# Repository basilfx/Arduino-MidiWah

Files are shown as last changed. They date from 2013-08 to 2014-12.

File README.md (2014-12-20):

# MidiWah v1.0
Arduino based bridge between a wah-wah (e.g. Dunlop GCB-95) and its potentiometer. Digitizes the potentiometer and feeds it via a digital potentiometer back to the circuit.

As a bonus, the digitized potentiometer signal can be  outputted via MIDI OUT.

## Contents
* Eagle schematic and PCB
* Arduino firmware

## Eagle

### Bill of materials
An Atmega328 can also be used. The R7-R9 are 0-ohm jumpers. The MCP4251 has a range of 0-100k.

| Part | Value | Device | Package |
|---|---|---|---|
| C1 | 22pF | C-EU025-024X044 | C025-024X044 |
| C2 | 22pF | C-EU025-024X044 | C025-024X044 |
| C3 | 1µF | CPOL-EUE2.5-5 | E2,5-5 |
| C4 | 1µF | CPOL-EUE2.5-5 | E2,5-5 |
| C5 | 100nF | C-EU025-024X044 | C025-024X044 |
| C6 | 100nF | C-EU025-024X044 | C025-024X044 |
| C7 | 100nF | C-EU025-024X044 | C025-024X044 |
| C8 | 100nF | C-EU025-024X044 | C025-024X044 |
| D1 | 1N4148 | 1N4148 | DO35-7 |
| IC1  | ATMEGA168 | MEGA8-P | DIL28-3 |
| IC2  | 7805L | 7805L | TO92 |
| IC3  | MCP4251 | MCP4251-104 | DIP254P762X533-14 |
| IC4  | 6N138 | 6N138 | DIL08 |
| Q1 | 16MHz | CRYSTALHC49S | HC49/S |
| R1 | 10k | R-EU_0204/7 | 0204/7 |
| R2 | 220 | R-EU_0204/7 | 0204/7 |
| R3 | 1k | R-EU_0204/7 | 0204/7 |
| R4 | 220 | R-EU_0204/7 | 0204/7 |
| R5 | 1k | R-EU_0204/7 | 0204/7 |
| R6 | 1k | R-EU_0204/2V | 0204V |
| R7 | 0 | R-EU_M0805 | M0805 |
| R8 | 0 | R-EU_M0805 | M0805 |
| R9 | 0 | R-EU_M0805 | M0805 |
| SW1  | | SW_DIP-4 | EDG-04 |

### Board render
The board measures 1.70x2.10 inch. Below a render of the top and bottom.

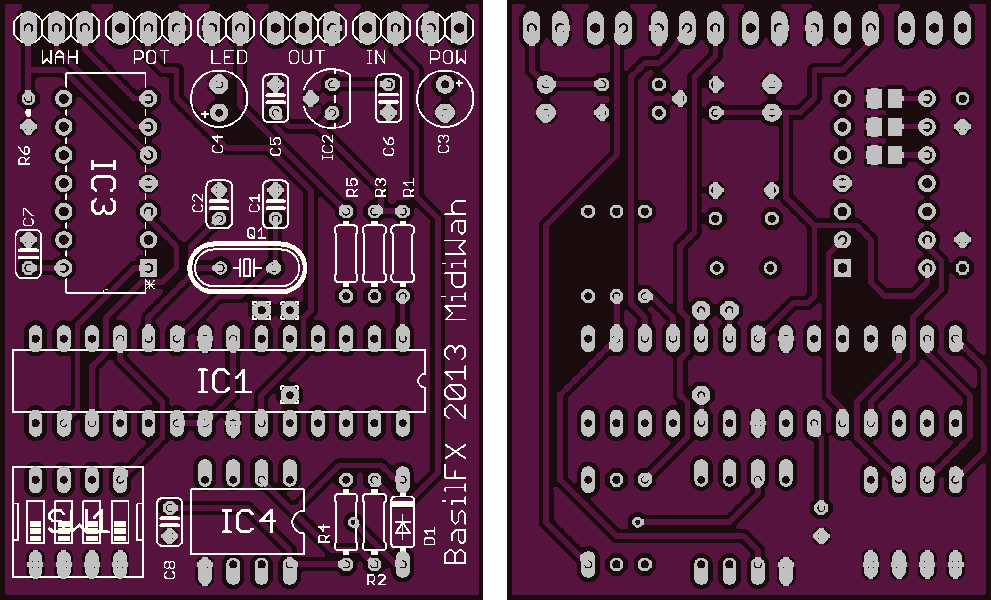
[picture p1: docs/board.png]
brd


## Arduino
The source can be found under `firmware`. It's build with Arduino 1.0.5, but newer versions should work too.

See the `firmware/UsedLibraries.md` for the libraries to install.

### Firmware
To be done.

### Configuration
The DIP switch on the PCB select the channel to which the MidiWah will respond

The firmware can be programmed via a few MIDI Control Change messages. Changes are only persisted when a save command is issued.

* `CC 80 [0|1]` &mdash; disable or enable calibration of the potentiometer. Replies with the same value.
* `CC 81 [0|1]` &mdash; disable or enable invertion of the potentiometer value. Replies with the same value.
* `CC 82 [0-2]` &mdash; select potentiometer program. Replies with the selected program, or the last one if program is invalid.
  * Program 0 is linear
  * Program 1 is logarithmic
  * Program 3 is first 50% from 0 to 127 and the next 50% from 127 to 0
* `CC 83 [x]` &mdash; save settings to EEPROM. The parameter `x` can be anything. Responds with same message.

## License
See the `LICENSE` file (MIT license).

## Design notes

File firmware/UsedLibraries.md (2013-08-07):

# Used Libraries
The libraries below are used and should be installed to compile this sketch.

## McpDigitalPot
Driver for the MCP4251 digital potentiometer.

URL: https://github.com/teabot/McpDigitalPot

## MIDI
MIDI protocol interface.

URL: http://playground.arduino.cc/Main/MIDILibrary

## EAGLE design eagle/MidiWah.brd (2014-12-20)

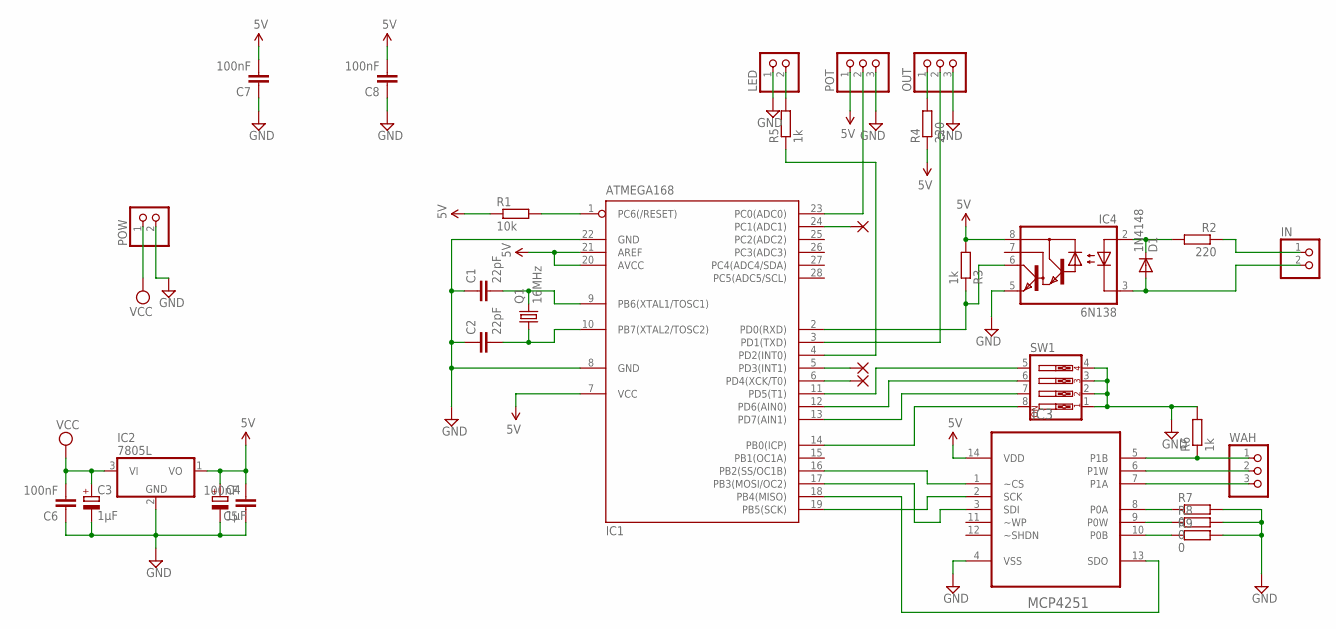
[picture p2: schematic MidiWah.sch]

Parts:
C1, C2: 22pF; C025-024X044
C3, C4: 1µF; E2,5-5
C5, C6, C7, C8: 100nF; C025-024X044
D1: 1N4148; DO35-7
IC1: ATMEGA168; DIL28-3
IC2: 7805L; TO92
IC3: MCP4251; DIP254P762X533-14
IC4: 6N138; DIL08
IN: PINHD-1X2; 1X02
LED: PINHD-1X2; 1X02
OUT: PINHD-1X3; 1X03
PAD1, PAD2, PAD3: WIREPAD1,6/0,8; 1,6/0,8
POT: PINHD-1X3; 1X03
POW: PINHD-1X2; 1X02
Q1: 16MHz; HC49/S
R1: 10k; 0204/7
R2, R4: 220; 0204/7
R3, R5: 1k; 0204/7
R6: 1k; 0204V
R7, R8, R9: 0; M0805
SW1: SW_DIP-4; EDG-04
WAH: PINHD-1X3; 1X03

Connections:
5V: C4.+, C5.2, C7.2, C8.2, IC1.7 (VCC), IC1.20 (AVCC), IC1.21 (AREF), IC2.1 (VO), IC3.14 (VDD), IC4.8 (VCC), POT.1, R1.1, R3.2, R4.1
GND: C1.1, C2.1, C3.-, C4.-, C5.1, C6.1, C7.1, C8.1, IC1.8 (GND), IC1.22 (GND), IC2.2 (GND), IC3.4 (VSS), IC4.5 (GND), LED.1, OUT.3, POT.3, POW.2, R6.2, R7.2, R8.2, R9.2, SW1.1, SW1.2, SW1.3, SW1.4
unnamed: IC1.1 (PC6(/RESET)), R1.2
unnamed: IC1.16 (PB2(SS/OC1B)), IC3.1 (~CS)
unnamed: C1.2, IC1.9 (PB6(XTAL1/TOSC1)), Q1.2
unnamed: C2.2, IC1.10 (PB7(XTAL2/TOSC2)), Q1.1
unnamed: IC1.19 (PB5(SCK)), IC3.2 (SCK)
unnamed: IC1.18 (PB4(MISO)), IC3.13 (SDO)
unnamed: IC1.17 (PB3(MOSI/OC2)), IC3.3 (SDI)
unnamed: D1.A, IC4.3 (C), IN.2
unnamed: D1.C, IC4.2 (A), R2.2
unnamed: IN.1, R2.1
unnamed: IC1.2 (PD0(RXD)), IC4.6 (VO), R3.1
unnamed: IC1.14 (PB0(ICP)), SW1.8
unnamed: IC1.13 (PD7(AIN1)), SW1.7
unnamed: IC1.12 (PD6(AIN0)), SW1.6
unnamed: IC1.11 (PD5(T1)), SW1.5
unnamed: IC1.23 (PC0(ADC0)), POT.2
unnamed: IC3.6 (P1W), WAH.2
unnamed: IC3.8 (P0A), R7.1
unnamed: IC3.7 (P1A), WAH.3
unnamed: IC1.3 (PD1(TXD)), OUT.2
unnamed: OUT.1, R4.2
unnamed: LED.2, R5.2
unnamed: IC1.4 (PD2(INT0)), R5.1
unnamed: IC3.5 (P1B), R6.1, WAH.1
unnamed: IC3.9 (P0W), R8.1
unnamed: IC3.10 (P0B), R9.1
unnamed: IC1.5 (PD3(INT1)), PAD2.1
unnamed: IC1.6 (PD4(XCK/T0)), PAD3.1
unnamed: IC1.24 (PC1(ADC1)), PAD1.1
VCC: C3.+, C6.2, IC2.3 (VI), POW.1

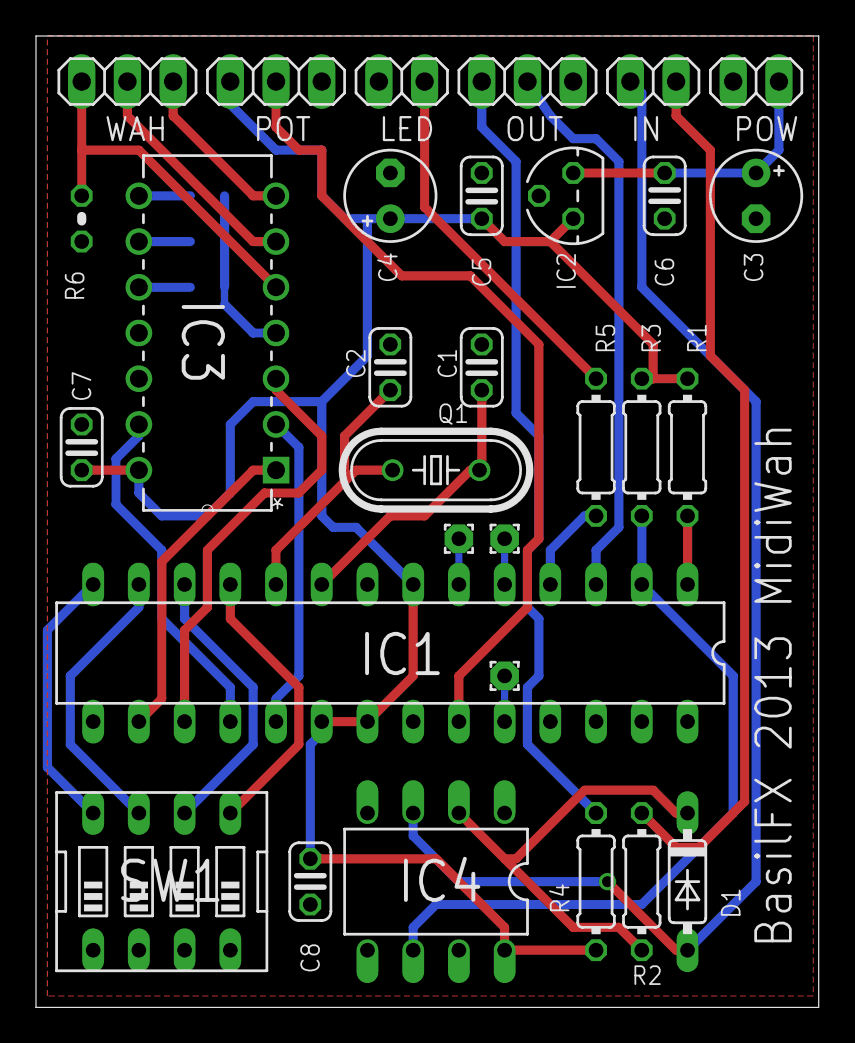
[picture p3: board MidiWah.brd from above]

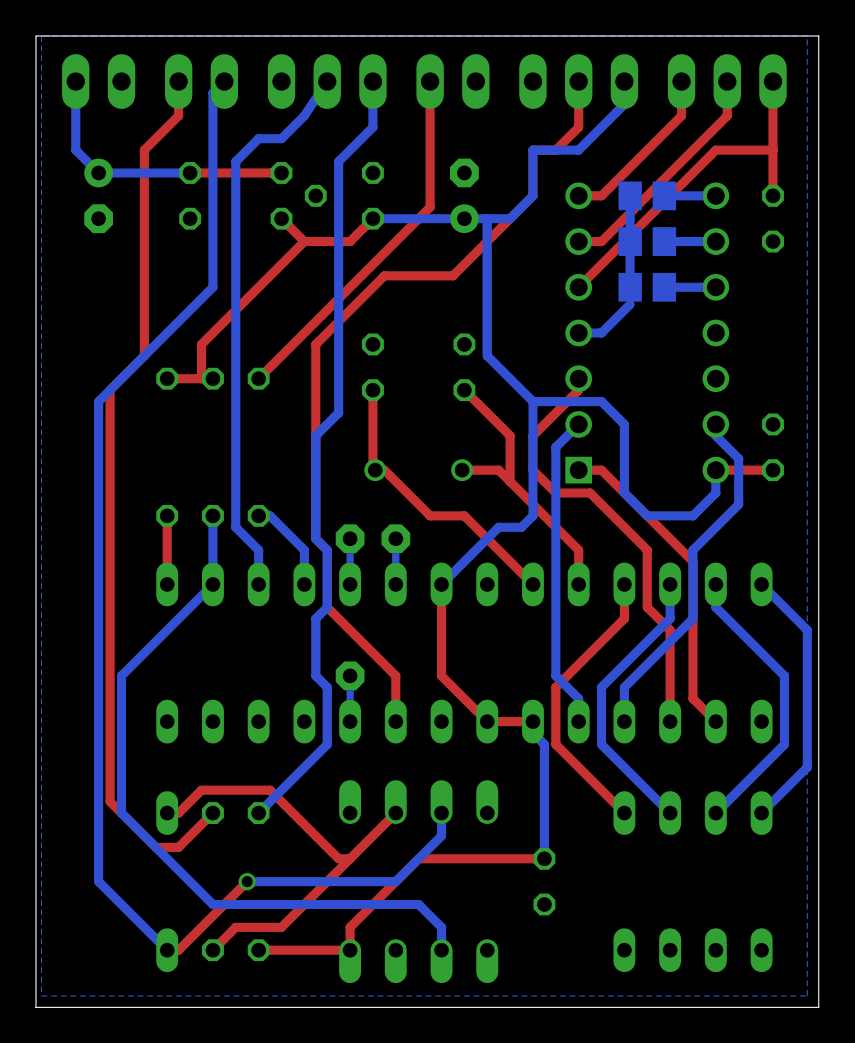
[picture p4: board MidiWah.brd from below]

Board: 2 copper layers, 43.5 x 54.0 mm, 33 parts (3 on the bottom side), 32 nets.

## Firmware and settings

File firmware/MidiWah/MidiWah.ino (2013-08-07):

#include <SPI.h>
#include <MIDI.h>
#include <EEPROM.h>
#include <McpDigitalPot.h>

#ifdef DEBUG
#include <SoftwareSerial.h>
#endif

#define SWITCH_1 5
#define SWITCH_2 6
#define SWITCH_3 7
#define SWITCH_4 8

#define MODE 3
#define SOFT_TX 2
#define SOFT_RX 9

#define POT_SS 10
#define WAH_IN 0

#define ADC_READINGS 10

struct AdcInfo {
  unsigned int readings[ADC_READINGS];
  unsigned int index;
  unsigned int total;
  unsigned int average;
};

struct Settings {
  unsigned int checksum;
  unsigned int adcMin;
  unsigned int adcMax;
  unsigned char program;
  boolean calibrate;
  boolean invert;
};

#ifdef DEBUG
SoftwareSerial Debug(SOFT_RX, SOFT_TX);
#endif
McpDigitalPot Potmeter = McpDigitalPot(POT_SS, 10000);

unsigned char lastChannel = 0;
unsigned char lastWah = 0;

AdcInfo adcWah;
Settings settings;

#define MAX_PROGRAM 3

unsigned char program1[] = {0, 0, 0, 0, 0, 0, 0, 0, 0, 0, 0, 1, 1, 1, 1, 1, 1, 1, 1, 1, 1, 1, 1, 1, 2, 2, 2, 2, 2, 2, 2, 2, 2, 3, 3, 3, 3, 3, 3, 3, 4, 4, 4, 4, 4, 5, 5, 5, 5, 6, 6, 6, 6, 7, 7, 7, 7, 8, 8, 9, 9, 9, 10, 10, 11, 11, 11, 12, 12, 13, 14, 14, 15, 15, 16, 17, 17, 18, 19, 19, 20, 21, 22, 23, 24, 25, 26, 27, 28, 29, 30, 31, 33, 34, 35, 37, 38, 40, 41, 43, 45, 46, 48, 50, 52, 54, 56, 59, 61, 63, 66, 68, 71, 74, 77, 80, 83, 86, 90, 93, 97, 101, 105, 109, 113, 118, 122, 127};
unsigned char program2[] = {0, 2, 4, 6, 8, 10, 12, 14, 16, 18, 20, 22, 24, 26, 28, 30, 32, 34, 36, 38, 40, 42, 44, 46, 48, 50, 52, 54, 56, 58, 60, 62, 64, 66, 68, 70, 72, 74, 76, 78, 80, 82, 84, 86, 88, 90, 92, 94, 96, 98, 100, 102, 104, 106, 108, 110, 112, 114, 116, 118, 120, 122, 124, 126, 126, 124, 122, 120, 118, 116, 114, 112, 110, 108, 106, 104, 102, 100, 98, 96, 94, 92, 90, 88, 86, 84, 82, 80, 78, 76, 74, 72, 70, 68, 66, 64, 62, 60, 58, 56, 54, 52, 50, 48, 46, 44, 42, 40, 38, 36, 34, 32, 30, 28, 26, 24, 22, 20, 18, 16, 14, 12, 10, 8, 6, 4, 2, 0};

void setup() {
  // Setup debug output
  #ifdef DEBUG
  Debug.begin(38400);
  Debug.println("Debug ready.");
  #endif

  // Load config
  loadConfig();
  
  // Configure pins
  pinMode(MODE, INPUT);  
  pinMode(SWITCH_1, INPUT);
  pinMode(SWITCH_2, INPUT);
  pinMode(SWITCH_3, INPUT);
  pinMode(SWITCH_4, INPUT);

  digitalWrite(MODE, HIGH);  
  digitalWrite(SWITCH_1, HIGH);
  digitalWrite(SWITCH_2, HIGH);
  digitalWrite(SWITCH_3, HIGH);
  digitalWrite(SWITCH_4, HIGH);
  
  // Setup Potmeter
  SPI.begin();
  SPI.setClockDivider(SPI_CLOCK_DIV2);
  Potmeter.scale = 127.0;
  
  // Setup MIDI
  MIDI.begin(MIDI_CHANNEL_OMNI);

  // Initialize ADC
  adcWah.average = 0;
  adcWah.total = 0;
  
  for (int i = 0; i < ADC_READINGS; i++) {
    adcWah.readings[i] = 0;
  }
}

void loop() {
  // Check for changed channel number
  unsigned char channel = getChannel();
  
  if (lastChannel != channel) {
    #ifdef DEBUG
    Debug.print("Channel changed to ");
    Debug.print(channel);
    Debug.println(".");
    lastChannel = channel;
    #endif

    MIDI.setInputChannel(channel);
  }
  
  // Handle MIDI-in
  if (MIDI.read()) {
    unsigned char type = MIDI.getType();
    
    if (type == ControlChange) {
      unsigned char control = MIDI.getData1();
      unsigned char value = MIDI.getData2();
 
      #ifdef DEBUG
      Debug.print("Control changed to ");
      Debug.print(control, HEX);
      Debug.print(" with value ");
      Debug.print(value, DEC);
      Debug.println(".");
      #endif

      switch (control) {
        case 0x43: // External control
          break;
        case 0x50: // Calibrate
          if (value == 1) {
            settings.calibrate = true;
            
            settings.adcMin = 512;
            settings.adcMax = 512;
            
            #ifdef DEBUG
            Debug.println("Calibrate is on."); 
            #endif

            // Send ack            
            MIDI.sendControlChange(0x50, 1, channel);
          } else {
            settings.calibrate = false;
            #ifdef DEBUG
            Debug.println("Calibrate is off.");
            #endif
          }

          // Send ack            
          MIDI.sendControlChange(0x50, 0, channel);
          
          break;
        case 0x51: // Invert
          if (value == 1) {
            settings.invert = true;
            
            #ifdef DEBUG
            Debug.println("Invert is on."); 
            #endif
            
            // Send ack            
            MIDI.sendControlChange(0x51, 1, channel);
          } else {
            settings.invert = false;
            
            #ifdef DEBUG
            Debug.println("Invert is off.");
            #endif
            
            // Send ack            
            MIDI.sendControlChange(0x51, 0, channel);
          }
          
          break;
        case 0x52: // Program
          if (value < MAX_PROGRAM) {
            settings.program = value;
            
            #ifdef DEBUG
            Debug.print("Program ");
            Debug.print(value, DEC);
            Debug.println(" selected.");
            #endif
          } else {
            #ifdef DEBUG
            Debug.print("Invalid program. Max program is ");
            Debug.print(MAX_PROGRAM, DEC);
            Debug.println(".");
            #endif
          }
          
          // Send ack            
          MIDI.sendControlChange(0x52, settings.program, channel);
          
          break;
        case 0x53: // Save
          saveConfig();
          
          // Send ack            
          MIDI.sendControlChange(0x53, 1, channel);

          break;
        default:
          break;
      }
    }
  }
 
  // Read new ADC value
  unsigned int wah = getWah();
  
  if (lastWah != wah) {
    #ifdef DEBUG
    Debug.print("Wah changed to ");
    Debug.print(wah, DEC);
    Debug.println(".");
    #endif
    
    lastWah = wah;
    
    // Output to MIDI
    MIDI.sendControlChange(0x43, wah, channel);
    
    // Update resistance
    Potmeter.setResistance(1, wah);
  }
}

void loadConfig() {
  for (unsigned int i = 0; i < sizeof(settings); i++) {
    *((char *) &settings + i) = EEPROM.read(i);
  }
  
  // Check for valid settings and if not, use defaults
  if (settings.checksum != 0xAAAA) {
    #ifdef DEBUG
    Debug.println("Settings checksum invalid. Using defaults.");
    #endif
    
    settings.checksum = 0xAAAA;
    settings.adcMin = 0;
    settings.adcMax = 1023;
    settings.calibrate = true;
    settings.invert = false;
    settings.program = 0;
    
    saveConfig();
  }

  #ifdef DEBUG
  Debug.println("Settings loaded from EEPROM.");  
  #endif
}

void saveConfig() {
  for (unsigned int i = 0; i < sizeof(settings); i++) {
    EEPROM.write(i, *((char*) &settings + i));
  } 
  
  #ifdef DEBUG
  Debug.println("Settings saved to EEPROM.");
  #endif
}

unsigned char getChannel() {
  unsigned char channel = 0x00;
 
  channel += !digitalRead(SWITCH_1) << 3;
  channel += !digitalRead(SWITCH_2) << 2;
  channel += !digitalRead(SWITCH_3) << 1;
  channel += !digitalRead(SWITCH_4) << 0;
  
  return channel + 1;
}

unsigned char getWah() {
  unsigned int reading = analogRead(WAH_IN);
  
  if (settings.calibrate) {
    if (reading > settings.adcMax) {
      settings.adcMax = reading;
    } else if (reading < settings.adcMin) {
      settings.adcMin = reading; 
    }
  }
  
  adcWah.total = adcWah.total - adcWah.readings[adcWah.index];
  adcWah.readings[adcWah.index] = reading;
  adcWah.total = adcWah.total + adcWah.readings[adcWah.index];
  adcWah.index = (adcWah.index + 1) % ADC_READINGS;
  adcWah.average = adcWah.total / ADC_READINGS;
  
  unsigned char result = map(adcWah.average, settings.adcMin, settings.adcMax, 0, 127);
  
  if (settings.program == 1) {
    result = program1[result];
  } else if (settings.program == 2) {
    result = program2[result];
  }
  
  if (settings.invert) {
    return result;
  } else {
    return 127 - result;
  }
}

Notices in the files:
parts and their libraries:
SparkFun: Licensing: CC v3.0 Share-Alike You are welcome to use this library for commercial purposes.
